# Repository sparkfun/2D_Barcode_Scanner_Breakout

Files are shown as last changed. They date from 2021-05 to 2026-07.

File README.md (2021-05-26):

2D Barcode Scanner Breakout
========================================

2D Barcode Scanner Breakout

[*2D Barcode Scanner Breakout (BOB-18088)*](https://www.sparkfun.com/products/18088)

The DYScan DE2120 is one of the coolest little barcode scanners we've ever seen. This tiny "scan engine" will read 20 different barcode symbologies — both 1D and 2D! This is achieved by using a camera coupled with on-board image processing to identify and decode everything from UPC codes to QR codes. The module also features two LEDs: one for illumination and one to project the red line that you're used to seeing from laser-based scanners. 

This breakout board makes it easy to explore all of the capabilities of the DE2120 without dealing with finicky flat flex cables. The scanner's USB interface is exposed via the on-board USB-C connector. A buzzer and status LED are connected to the module through appropriate drive circuits and a pushbutton tactile switch is provided on the "trigger" pin. When you're ready to incorporate the module into your embedded project, you can leverage the 5 pin header for direct access to the TTL serial pins, power pins, and trigger input.

The module can be configured either by using the serial interface or by scanning command barcodes found in the datasheet.

Repository Contents
-------------------
* **/Documentation** - Datasheet & Settings Manual
* **/Hardware** - Eagle design files (.brd, .sch)

Documentation
--------------
* [SparkFun DE2120 Arduino Library](https://github.com/sparkfun/SparkFun_DE2120_Arduino_Library)
* [SparkFun DE2120 Python Package](https://github.com/sparkfun/DE2120_Py)
* [2D Barcode Scanner Breakout Hookup Guide](https://learn.sparkfun.com/tutorials/2d-barcode-scanner-breakout-hookup-guide)

Product Versions

* [BOB-18088](https://www.sparkfun.com/products/18088)
* [SPX-16441](https://www.sparkfun.com/products/16441)
* [SPX-16410](https://www.sparkfun.com/products/16410)

License Information
-------------------

This product is _**open source**_! 

Please review the LICENSE.md file for license information. 

If you have any questions or concerns on licensing, please contact technical support on our [SparkFun forums](https://forum.sparkfun.com/viewforum.php?f=152).

Distributed as-is; no warranty is given.

- Your friends at SparkFun.

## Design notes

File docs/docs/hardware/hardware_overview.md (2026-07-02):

# Hardware Overview

Let's take a closer look at the DYScan DE2290 scanner module as well as the other hardware on the 2d Barcode Scanner Breakout - V2.

## DE2290 Barcode Scanner Module

The DE2290 barcode scanner module from DYScan combines a CMOS camera with on-board image processing to identify and decode 20 different barcode symbologies in both 1D and 2D on a variety of mediums (paper, screen, etc.). The DE2290 also includes two user-configurable LEDs. One super bright white LED to help illuminate the scanning area and one red LED to project the red line like those found on laser-based scanners.

The DE2290 interfaces over USB Serial and TTL UART and can operate in several modes including USB Keyboard (default), USB COM, USB HID and TTL. Configure the communication modes and other settings by scanning barcodes or sending serial commands from the [Scan Settingss Manual](/ref/DY%20SCAN%202D%20barcode%20scanner%20DE2290D.%20DE2290H%20setting%20manual.pdf). 

When in USB Keyboard mode, the scanner behaves as a keyboard input (think your typical scanner on a Point of Sale system) and "types" the scanned barcode data followed by a carriage return. In USB-COM mode, the scanner behaves as a USB COM device and in TTL mode, the scanner operates as a TTL UART device to interface with a controller.

The module's two LEDs are also fully configurable to set behavior, brightness and simple on/off settings.

As mentioned above, the DE2290 can recognize and scan many different 1D and 2D symbologies. The list below outlines all the barcode symbologies the module recognizes:

**1D Symbologies**

* UPC-A
* UPC-E
* EAN-8
* EAN-13
* Code 128
* GS1-128
* Code 39
* Code 93
* Code 11
* Interleaved 2-of-5
* Matrix 2-of-5
* Industrial 2-of-5
* Codabar
* MSI
* GS1 DataBar
* Datalogic 2-of-5

**2D Symbologies**

* QR Code
* Data Matrix
* PDF 417
* Micro PDF 417
* Aztec Code

## Pinout and USB-C Connection

The scanner module receives power either via the USB-C connector or from a regulated **3.3V** source through the **3.3V** pin. The scanner requires at least **190mA@3.3V** to function. **5V** from USB is regulated to **3.3V** through an on-board **3.3V/600mA** regulator.

The breakout routes the power input pins (**3.3V** and Ground), Serial UART (RX/TX) pins as well as the Trigger Input and Status Output pins to a standard 0.1"-spaced PTH header to easily interface with them when integrating the module breakout in an installation. 

## Buzzer, Status LED and Trigger Button

We've routed the trigger pin to a pushbutton labeled SCAN, the status LED pin to a green LED and buzzer pin to a Piezo buzzer. Configure the Trigger and Buzzer just like everything else on the DE2290 using serial commands or barcodes from the [Scan Settings Manual](/ref/DY%20SCAN%202D%20barcode%20scanner%20DE2290D.%20DE2290H%20setting%20manual.pdf). 

Use the Trigger Button (or pin) to initiate a scan when the DE2290 is in Trigger Mode (default). The buzzer defaults to play a tone on power-up and on a successful decode. The STAT LED illuminates on power-up and on a successful scan. The STAT LED is not configurable through software but can be disabled through the STAT LED Jumper.

## Solder Jumpers

The 2D Barcode Scanner Breakout has three jumpers labeled <code>**PWR**</code>, <code>**STAT_LED**</code> and <code>**BUZZ**</code>. These three jumpers all complete their respective circuits and are **CLOSED** by default.

The Power LED Jumper connects the anode of the power LED to **3.3V** through a **1k&ohm;** resistor. Open the jumper by severing the trace between the two pads to disable the Power LED.

The STAT LED Jumper connects the anode of the status LED to a transistor via a **1k&ohm;** resistor so it can be controlled by the barcode module. Open the jumper to permanently disable the Status LED on the breakout. Disabling this LED is recommended if you are using an external LED connected to the STAT PTH pin.

The Buzzer Jumper completes the buzzer driver circuit and connects the voltage input (positive) pin of the buzzer to **3.3V** via a **10&ohm;** resistor. Open the jumper to disable the on board buzzer. Similar to the STAT LED, opening this jumper is particularly useful when an external buzzer is connected to the buzzer driver PTH pin.

## Board Dimensions

The 2D Barcode Scanner Breakout measures 1.75in x 1.00in (44.45mm x 25.4mm) with two mounting holes that fit a [4-40 screw](https://www.sparkfun.com/products/10453).

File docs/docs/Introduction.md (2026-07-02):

---
slug: /
---

# Introduction

<figure>
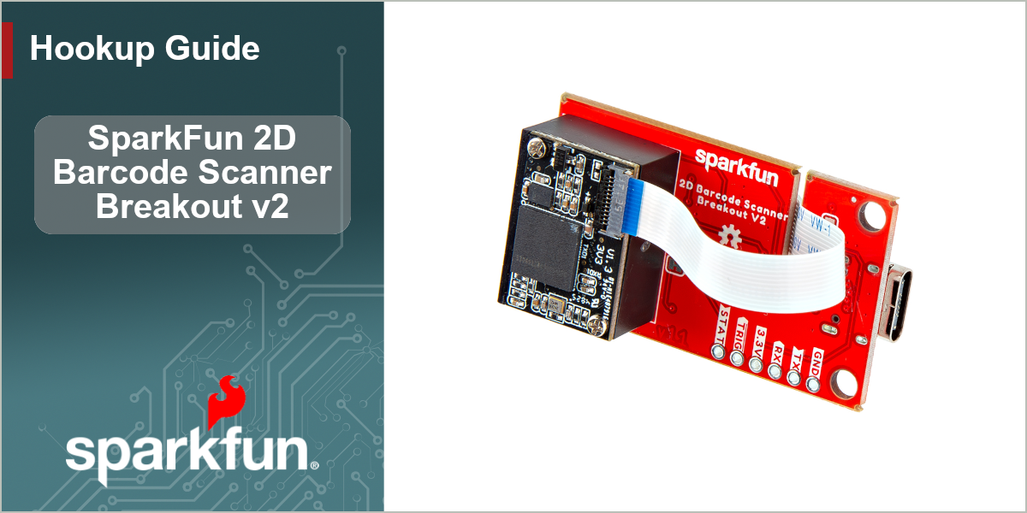
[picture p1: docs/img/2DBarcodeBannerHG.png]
2D Barcode Scanner Hookup Guide Banner Image (https://www.sparkfun.com/sparkfun-2d-barcode-scanner-breakout-v2.html)

</figure>

The [SparkFun 2D Barcode Scanner Breakout - V2](https://www.sparkfun.com/sparkfun-2d-barcode-scanner-breakout-v2.html) is a nifty little breakout board featuring the DE2290 barcode scanner module from DYScan. The DE2290 reads 20 different barcode symbologies (both 1D and 2D) using a camera coupled with on-board image processing to identify and decode everything from UPC codes to QR codes. The module also features two LEDs: one for illumination and one to project the red line for "aiming" that you're used to seeing from laser-based scanners.

The breakout makes it easy to use the scanner module by connecting the scanner's USB serial output to a USB-C connector. The breakout also includes a standard 0.1"-spaced PTH header for power, serial UART, trigger and status output connections. On top of that, we've added a trigger button, buzzer and status LED connected to the appropriate drive circuits to easily initialize scans and receive feedback from scanning barcodes.

**Note About Versions**

This version of the 2D Barcode Scanner Breakout (V2) is physically identical to the previous version and the DE2290 functions the same as the DE2120 but uses a different naming convention for the command set. This version works as a drop-in replacement but must use the updated commands. The previous version's Arduino library and Python package have been ported to new versions that use the DE2290 command set. The silkscreen on this version reads "2D Barcode Scanner V2". Refer to the image below to make sure you are using the correct version:

<figure>
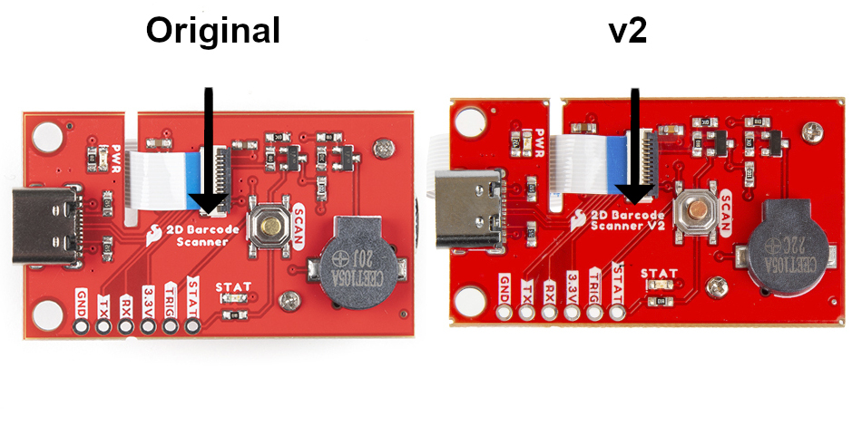
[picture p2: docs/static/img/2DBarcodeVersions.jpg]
Photo showing version indicator

</figure>

## Topics Covered

This guide contains three main sections: **Quickstart Guide**, **Hardware** and **Software**. 

The Quickstart Guide covers how to plug the Barcode Scanner Breakout into a computer over USB and use it as a COM device to scan codes and print them out in a serial terminal. 

The Hardware section provides a detailed overview of the DE2290 and other hardware on the 2D Barcode Scanner Breakout and covers how to connect the breakout to both a computer as well as a SparkFun RedBoard to use it with the Arduino IDE.

The Software section covers how to install the SparkFun DE2290 Arduino Library along with brief overviews of some of the examples included in the library.

## Resources and Support Documentation

You'll find the board design files (Eagle files & schematic), relevant documentation (datasheets, white papers, etc.) and other helpful links in the **Resources**. Lastly, the **Support** section includes a Troubleshooting page that includes any helpful tips specific to this board as well as information on how to receive technical support from SparkFun.

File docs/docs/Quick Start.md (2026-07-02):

# Quick Start Guide

In this Quick Start Guide we'll show how to connect the 2D Barcode Scanner - V2 to a computer over USB, operate it as a COM device to scan barcodes and print out the scanned codes to a serial terminal. This guide assumes users know how to interact with a COM device using a serial terminal. If you're unfamiliar with using serial terminals or would prefer to use the 

## USB Assembly

Start by connecting the Barcode Scanner Breakout to a computer with a USB-C cable. 

<figure>
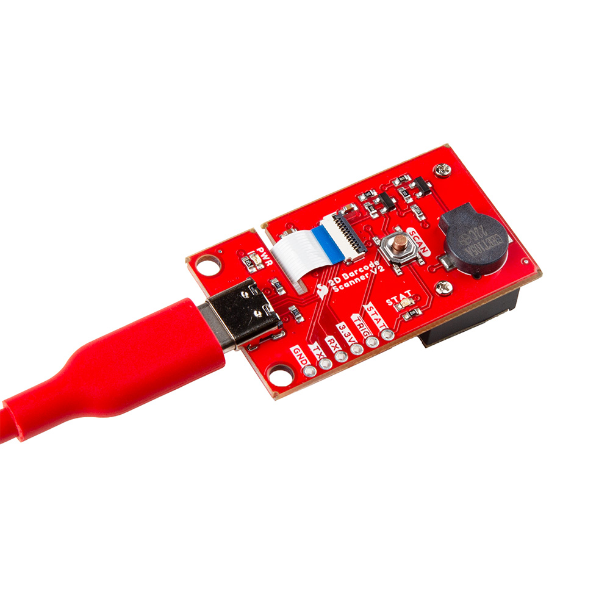
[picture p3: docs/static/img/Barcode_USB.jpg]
Barcode Scanner Breakout connected over USB

</figure>

Next, find scan the USB-COM Mode barcode from the [Scan Settings Manual](/ref/DY%20SCAN%202D%20barcode%20scanner%20DE2290D.%20DE2290H%20setting%20manual.pdf) (the DE2290 defaults to USB-Keyboard mode) on page 35 or you can scan it directly below:

<figure>
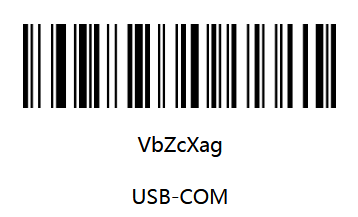
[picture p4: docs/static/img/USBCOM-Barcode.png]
USB-COM Mode barcode from the Scan Settingss Manual

</figure>

The DE2290 defaults to operate in Trigger Mode to scan barcodes so you'll need to press the trigger button to initiate a scan. Once the DE2290 is in USB-COM mode, your computer should automatically download and install the device's driver if needed. 

## Serial Terminal Scanning

With the drivers installed and the Barcode Scanner Breakout in USB-COM mode, open a serial terminal of your choice like [TeraTerm](https://teratermproject.github.io/index-en.html) to the COM port with the baud set to **115200**. 

The DE2290 defaults to operate in Trigger Mode to scan barcodes so you'll need to press the trigger button for each scan. Find some barcodes to scan or if you don't have any readily available, you can generate custom codes from all types of symbologies on [this website](https://barcode.tec-it.com/en) to make sure the barcode scanner is working properly.

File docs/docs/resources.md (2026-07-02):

For more information about the 2D Barcode Scanner Breakout v2, take a look at the following resources:

* [Schematic](/ref/2D_Barcode_Scanner_Breakout.pdf)
* [Eagle Files](/ref/2D_Barcode_Scanner_Breakout.zip)
* [Datasheet](/ref/DY%20SCAN%202D%20barcode%20module%20DE2290D%20Specification%20(1).pdf)
* [Scan Settings Manual](/ref/DY%20SCAN%202D%20barcode%20scanner%20DE2290D.%20DE2290H%20setting%20manual.pdf)
* [DE2290 Arduino Library](https://github.com/sparkfun/SparkFun_DE2290D_Arduino_Library)
* [DE2290 Python Package](https://github.com/sparkfun/DE2290D_Py)

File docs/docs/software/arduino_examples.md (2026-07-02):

# Arduino Examples

The DE2290 Library includes three examples to demonstrate how to do simple scans, read the barcode data, configure the various settings available and sending specific commands. In this section we'll go over these examples in some detail and highlight important bits of code.

**Important:** Make sure to scan the barcode below to put the DE2290 into TTL mode or the barcode scanner will not communicate properly with the Arduino and the examples will freeze until the board is reset.

<figure>
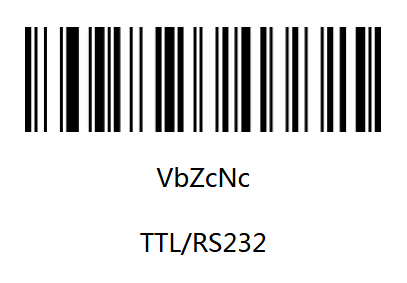
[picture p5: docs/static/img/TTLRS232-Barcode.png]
DE2290 TTL Mode Barcode
[]
</figure>

The 2D Barcode Scanner saves all settings during power cycles so you can configure the DE2290 however you would like (e.g. scanning mode, image flipping, LED settings, etc.) prior to assembling your Arduino circuit and using the examples.

## Example 1 - Serial Scan

This basic example demonstrates how to connect the scanner to an Arduino via Software Serial and output any barcodes it sees over serial. Open the example in Arduino by navigating to **"File > Examples > SparkFun DE2290 Arduino Library > 
Example1-SerialScan"**. Select the correct Board and Port from the **"Tools"** menu and click upload. After the upload finishes, open the [serial monitor](https://learn.sparkfun.com/tutorials/terminal-basics) with the baud set to **115200**.

Since this example uses the Software Serial library, make sure to refer to [this page](https://www.arduino.cc/en/Reference/softwareSerial) for pin compatibility limitations for common Arduino boards. The example defaults to use pins D16 and D17 on the RedBoard IoT - ESP32 so if you prefer a different board, adjust this line:

``` c++
SoftwareSerial softSerial(2, 3);
```

After declaring the pins to use for RX/TX in Software Serial, the code creates the scanner object as well as the scanner buffer and buffer size:

``` c++
DE2290 scanner;
    
#define BUFFER_LEN 40
char scanBuffer[BUFFER_LEN];
```
The setup attempts to initialize the barcode scanner and, if successful, the main loop will start polling the buffer for any data every 200ms. If there is data in the buffer, the code prints it. With a serial monitor open, try scanning barcodes with the breakout and watch the code data print out.

## Example 2 - Serial Settings

The second example shows how to adjust a selection of seven scanner settings using a "menu" in the serial monitor. Select and upload the example and open a serial monitor with the baud set to **115200**. After initializing the DE2290, the code prints out the selection options for the user.

<figure>
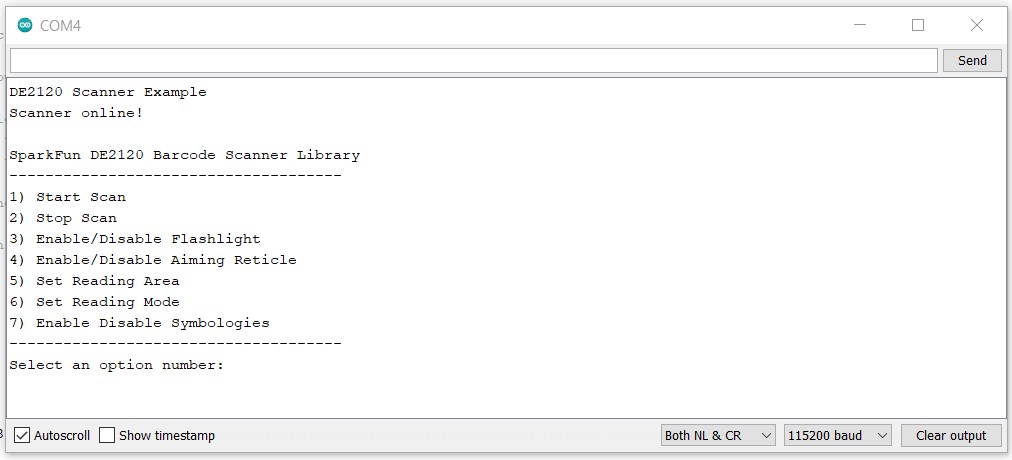
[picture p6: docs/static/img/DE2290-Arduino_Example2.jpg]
Screenshot showing Arduino Serial Monitor of options menu

</figure>

Select an option number by sending the corresponding number and hit <kbd>ENTER</kbd>. The code then prints out the available options for the selected setting. Enter the number corresponding to the preferred behavior and hit <kbd>ENTER</kbd> again to change the setting. After the setting is adjusted, the code prints if the adjustment was successful and returns to the "main menu".

## Example 3 - Send Command

The third example demonstrates how to use the `sendCommand();` function to send serial commands to the barcode scanner either through scanning barcodes or a serial monitor. As we mentioned in the previous section, `sendCommand();` takes two strings, links them together, adds the command prefix ("^_^") and suffix (".") and sends the command to the DE2290. 

Upload the example and open the serial monitor with the baud set to **115200**. Once the terminal window is open, type in the command you want to use and press <kbd>ENTER</kbd>. Refer to the [Scan Settingss Manual](/ref/DY%20SCAN%202D%20barcode%20scanner%20DE2290D.%20DE2290H%20setting%20manual.pdf) for the Command Table (found starting on page 78). If the command is not recognized, the code prints out the code is invalid.

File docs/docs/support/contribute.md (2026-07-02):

# Contribute

## Improve our Documentation

All of this documentation can be modified by you! Please help us make it better.

* These pages are contained in the [`docs` folder of the SparkFun 2D Barcode Scanner Breakout repository](https://github.com/sparkfun/2D_Barcode_Scanner_Breakout/tree/main/docs).

### Submit a Correction

1. Fork this repo
2. Add your corrections or improvements to the markdown file
3. File a pull request with your changes, and enjoy making the ~~words~~ ~~worlds~~ world a better place.
    * Once received, the documentation specialist will automatically be notified.
    * We will review your suggested improvements to make sure they are correct and fit within our documentation standards.

## Improve our Hardware Design

This hardware design is open-source! Please help us make it better.

* Our board design files are contained in the [`Hardware` folder of the SparkFun 2D Barcode Scanner Breakout repository](https://github.com/sparkfun/2D_Barcode_Scanner_Breakout_IoT_9DoF/tree/main/Hardware).

### Submit a Design Improvement

1. Fork this repo
2. Add your design improvements
3. File a pull request with your changes, and enjoy making the ~~words~~ ~~worlds~~ world a better place.
    * Once received, the engineer in charge of the original design will automatically be notified.
    * We will review your suggested improvements, if they are within our board design standards and meet our product design requirements, we will flag these changes for our next board revision. *(Please note, that even if your suggestion is accepted, these changes may not be immediate. We may have to cycle through our current product inventory first.)*

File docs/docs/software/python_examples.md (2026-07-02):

# DE2290 Python Package Examples

The DE2290 Python package includes three examples to demonstrate the basics of using the 2D Barcode Scanner Breakout with Python. In this section we'll cover the examples and highlight how they work.

To use the examples, open them from the DE2290 Py location or copy the code from the [GitHub Repository](https://github.com/sparkfun/DE2290_Py/tree/main/examples) into your preferred Python interpreter.

**Reminder:** The DE2290 Python Package communicates with the 2D Barcode Scanner Breakout over USB so make sure to set the DE2290 to USB-COM mode by scanning the barcode below or sending the appropriate serial command:

<figure>
DE2290 TTL Mode Barcode
</figure>

The 2D Barcode Scanner saves all settings during power cycles so you can configure the DE2290 however you would like (e.g. scanning mode, image flipping, LED settings, etc.) prior to using the examples.

## Example 1 - Serial Scan

This basic example demonstrates how to initialize the barcode scanner and output any barcodes it reads. The example attempts to initialize the barcode scanner and, if successful, starts polling the buffer for any data every 200ms. If there is data in the buffer, the code prints it. With a terminal window open to the correct port, try scanning barcodes with the breakout and watch the decoded barcode data print out.

## Example 2 - Serial Settings

This example shows how to configure various settings for the DE2290 using serial inputs sent over USB. The code creates an interactive menu for starting and stopping a scan along with the settings listed below:

* Enable/Disable Flashlight
* Enable/Disable Aiming Reticle
* Enable/Disable Decode Beep
* Enable/Disable Start Up Beep
* Change Buzzer Frequency
* Enablde/Disable Image Flipping
* Set Reading Area
* Set Reading Mode
* Enable/Disable Symbologies

Run the example and open a terminal window to the Barcode Scanner's port. To adjust a setting, type in the corresponding number and hit ENTER. A second menu for will open with the available options for the setting. Type in the number matching the preferred option and hit ENTER again. The code prints out if the setting is adjusted successfully and then returns to the main menu.

## Example 3 - Send Command

The third example demonstrates how to use the `send_command` function to send specific command strings to the DE2290. The `send_command` function takes two strings, links them together, adds the command prefix ("^_^") and suffix (".") and sends the command to the DE2290. 

Run the example and open a terminal window to the Barcode Scanner's port. Once the terminal window is open, type in the command you want to use and press ENTER. Refer to the [Scan Settings Manual](/ref/DY%20SCAN%202D%20barcode%20scanner%20DE2290D.%20DE2290H%20setting%20manual.pdf) for the Command Table. If the command is not recognized, the code prints out the code is invalid.

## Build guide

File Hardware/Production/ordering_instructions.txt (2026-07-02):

panel size, 111x117mm
PCB thickness, 1.6mm
number of layers, 2
soldermask color, Red
silkscreen color, White
oz copper, 1oz
finish, HASL lead free
stencils, top
pcs per panel, 8
min trace width, 0.1778mm / 0.0070in
min drill size, 0.3810mm / 0.0150in

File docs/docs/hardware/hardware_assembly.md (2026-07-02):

# Hardware Assembly

Now that we're familiar with the DE2290 and other hardware present on the 2D Barcode Scanner Breakout, let's get it connected and start scanning codes.

## USB Assembly

The easiest way to get started with the barcode scanner breakout is to plug it in to a computer (PC or SBC) via a USB-C cable. Simply connect the breakout to your computer using a USB-C cable and scan the USB-COM mode barcode from the [Scan Settings Manual](/ref/DY%20SCAN%202D%20barcode%20scanner%20DE2290D.%20DE2290H%20setting%20manual.pdf) (the DE2290 defaults to USB-Keyboard mode) on page 23 or you can scan directly it below:

<figure>
USB-COM Mode barcode from the Scan Settingss Manual
</figure>

Once the device is in USB-COM Mode your computer should automatically search for and install the necessary drivers. After drivers are installed and the device has enumerated, select the correct port and open up a terminal window with the baud to **115200**. 

The DE2290 defaults to trigger mode to scan barcodes so the Trigger Button must be pressed to start a scan. Find some barcodes to scan or if you don't have any readily available, you can generate custom codes from all types of symbologies on [this website](https://barcode.tec-it.com/en) to quickly test the barcode scanner. 

<figure>
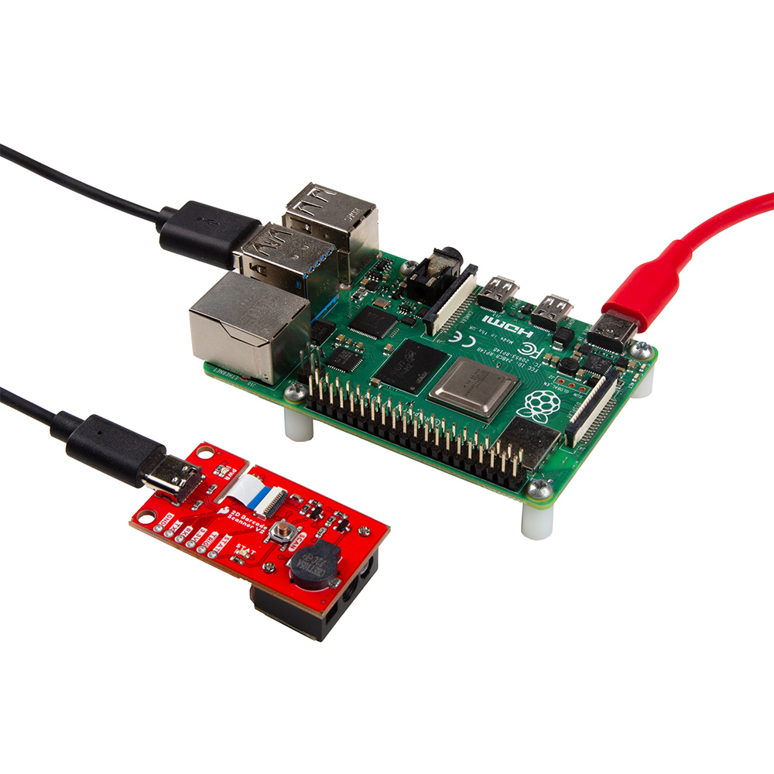
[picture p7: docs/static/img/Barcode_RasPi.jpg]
Completed USB assembly with a Raspberry Pi

</figure>

## Serial UART Assembly

Interacting with the 2D Barcode Scanner Breakout via TTL UART either through direct commands from the Scan Settings Manual or with the Arduino library requires a bit of soldering and wiring. As covered in the previous seciton, the breakout routes the required TTL UART pins to a 0.1"-spaced header for users to solder to. If you are not familiar with through-hole soldering, we recommend reading through [this tutorial](https://learn.sparkfun.com/tutorials/how-to-solder-through-hole-soldering). **Reminder:** The barcode scanner requires **190mA@3.3V** so make sure your chosen microcontroller can source enough current through the **3.3V** output to power the scanner.

For easy prototyping in this tutorial we're going to solder a set of [male headers](https://www.sparkfun.com/products/116) to the breakout to easily prototype circuits using either a breadboard or jumper wires. After soldering to the breakout, we make the necessary connections to the controller. In this case we'll use a SparkFun RedBoard to demonstrate the Arduino library so make the following connections or match the photo below:

* **3.3V** -> **3.3V**
* **GND** -> **Ground**
* **TX** -> **16**
* **RX** -> **17**

<figure>
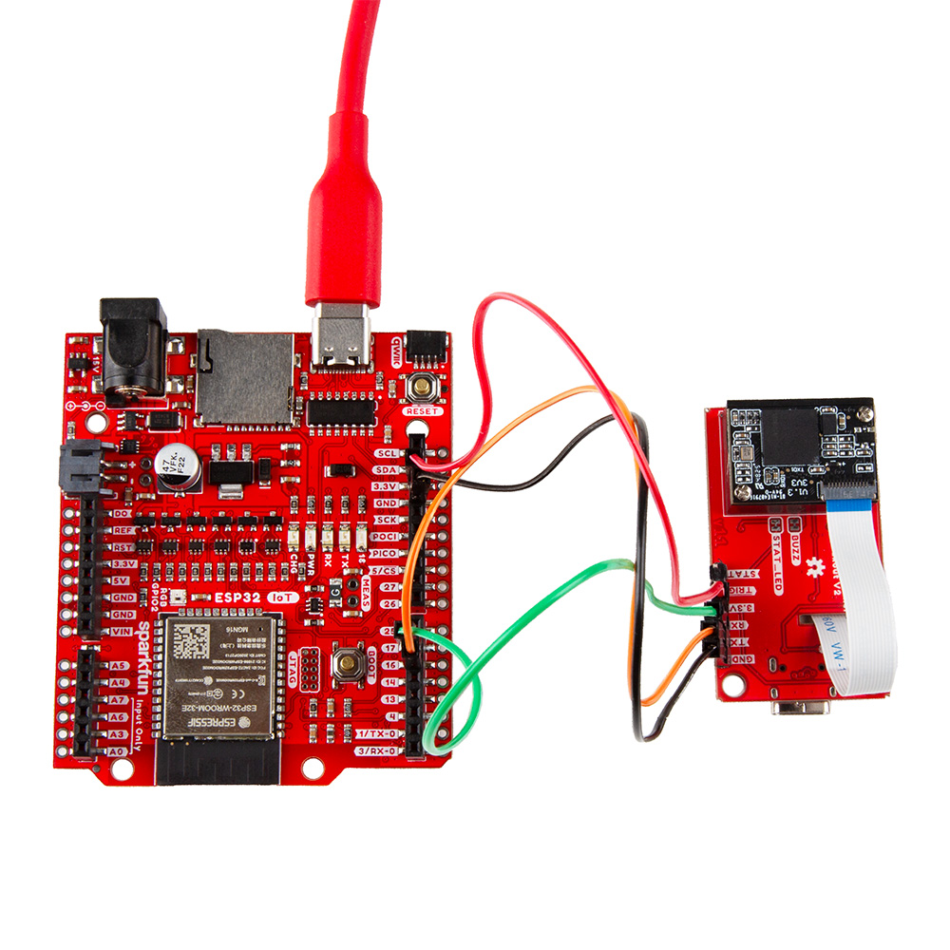
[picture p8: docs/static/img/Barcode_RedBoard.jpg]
Completed assembly with the RedBoard IoT

</figure>

After assembling the circuit, make sure to set the 2D Barcode Scanner Breakout to operate in TTL mode by scanning the proper barcode from the [Scan Settings Manual](/ref/DY%20SCAN%202D%20barcode%20scanner%20DE2290D.%20DE2290H%20setting%20manual.pdf) on page 24 or you can scan it with the barcode reader below:

<figure>
DE2290 TTL Mode Barcode
</figure>

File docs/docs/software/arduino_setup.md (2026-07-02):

# DE2290 Arduino Library Setup

## SparkFun DE2290

The SparkFun DE2290 Arduino Library helps to interface an Arduino microcontroller with the barcode scanner to configure common settings as well as poll the device for scanned codes. Note, the library does not cover all of the codes from the [Scan Settings Manual](/ref/DY%20SCAN%202D%20barcode%20scanner%20DE2290D.%20DE2290H%20setting%20manual.pdf); just the ones we found particularly useful.

Install the Arduino Library Manager by searching for **"SparkFun DE2290 Arduino Library"** and clicking the "Install" button to download and install the latest version. Users who prefer to manually install the library can get it from the [GitHub Repository](https://github.com/sparkfun/SparkFun_DE2290_Arduino_Library).

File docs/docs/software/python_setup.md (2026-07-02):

# DE2290 Python Package Setup

The SparkFun DE2290 Python package helps streamline sending commands and receiving barcode data from the 2D Barcode Scanner Breakout. Install the `sparkfun-de2290d` Python package hosted by PyPi through a command interface or if you prefer to manually download and build the libraries from the [GitHub Repository](https://github.com/sparkfun/DE2290D_Py), 

## Installation

The Raspberry Pi OS should automatically install any necessary drivers for the 2D Barcode Scanner when it is connected and operating in USB-COM Mode. Find the USB-COM barcode on page 23 in the [Scan Settings Manual](/ref/DY%20SCAN%202D%20barcode%20scanner%20DE2290D.%20DE2290H%20setting%20manual.pdf) (the DE22900 defaults to USB-Keyboard mode) or scan it below:

<figure>
USB-COM Mode barcode from the Scan Settingss Manual
</figure>

### PyPi Installation

The DE2290 Py repository is hosted on PyPi as the `sparkfun-de22902` package. On systems that support PyPi, install the package via `pip3` (use `pip` for Python 2) using the following commands:

For **all users** (The user must have **[sudo](https://en.wikipedia.org/wiki/Sudo)** privileges):

``` bash
    sudo pip3 install sparkfun-DE2290
```

For the **current user**:

``` bash
    pip3 install sparkfun-DE2290
```
### Local Installation

Make sure to install the `setuptools` package on the system.

Direct installation at the command line (use `python` for Python 2):

``` bash
    python3 setup.py install
```    
Use the following command to build a package for use with `pip3`:

``` bash
    python3 steup.py sdist
```

A package file is built and placed in a subdirectory called dist. Install the package file using `pip3`.

``` bash
    cd dist
    pip3 install sparkfun_DE2290-<version>.tar.gz
```
### DE2290 Python Package Operation

For a full overview of how to use this package along with all the functions included with the DE2290 Py package, take a look at the [source code](https://github.com/sparkfun/DE2290D_Py/blob/main/de2290D_barcode_scanner.py).

### Upgrading the Python Package

If needed, the DE2290 Python package can be upgraded using the following commands:

For **all users**:

``` bash
    sudo pip3 install --upgrade sparkfun-DE2290
```

For the **current user**:

``` bash
    pip3 install --upgrade sparkfun-DE2290
```

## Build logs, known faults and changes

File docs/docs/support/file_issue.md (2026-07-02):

# Submit Issues

## Support

If you need technical assistance and more information on a product that is not working as you expected, visit the [SparkFun Community](https://community.sparkfun.com). The community forums are monitored by the SparkFun Technical Support Team and the SparkFun community as a whole.

## Existing Issue

Spot something wrong? Please check the list of reported and fixed issues  .  in this repository.

## Discrepancies in the Documentation

All of this documentation can be modified by you! Please help us make it better.

* The documentation files for these pages are contained in the [`docs` folder of the SparkFun 2D Barcode Scanner Breakout repository](https://github.com/sparkfun/2D_Barcode_Scanner_Breakout/tree/main/docs).

### Spot something wrong?

If a section of the documentation is incorrect, please [open an issue](https://github.com/sparkfun/2D_Barcode_Scanner_Breakout/issues) and let us know.

### Do you have a suggested correction?

1. With a GitHub account, fork this repo
2. Add your correction(s) or improvement(s) to the markdown file(s)
3. File a pull request with your changes, and enjoy making the ~~words~~ ~~worlds~~ world a better place.
    * Once received, the documentation specialist will automatically be notified.
    * We will review your suggested improvement(s) to make sure they are correct and fit within our documentation standards.

## Problems in the Hardware Design

All of our designs are open-source! Please help us make it better.

* Our board design files are contained in the [`Hardware` folder of the SparkFun 2D Barcode Scanner Breakout repository](https://github.com/sparkfun/2D_Barcode_Scanner_Breakout/tree/main/Hardware).

### Does something not make sense?

If part of the design is confusing, please [open an issue](https://github.com/sparkfun/2D_Barcode_Scanner_Breakout/issues) and let us know.

### Did we forget to include an important function of the board?

Please keep in mind that we may intentionally exclude certain functions of the board to meet our product design requirements.

If part of the board's functionality is missing, please [open an issue](https://github.com/sparkfun/2D_Barcode_Scanner_Breakout/issues) and file a feature request.

### Do you wish to contribute directly to improving the board design?

1. With a GitHub account, Fork this repo
2. Add your design improvement(s)
3. File a pull request with your changes, and enjoy making the ~~words~~ ~~worlds~~ world a better place.
    * Once received, the engineer in charge of the original design will automatically be notified.
    * We will review your suggested improvement(s), if they are within our board design standards and meet our product design requirements, we will flag these changes for our next board revision. *(Please note, that even if your suggestion is accepted, these changes may not be immediate. We may have to cycle through our current product inventory first.)*

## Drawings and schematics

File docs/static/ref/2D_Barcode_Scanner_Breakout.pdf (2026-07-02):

3.3V

## 3.3V GND

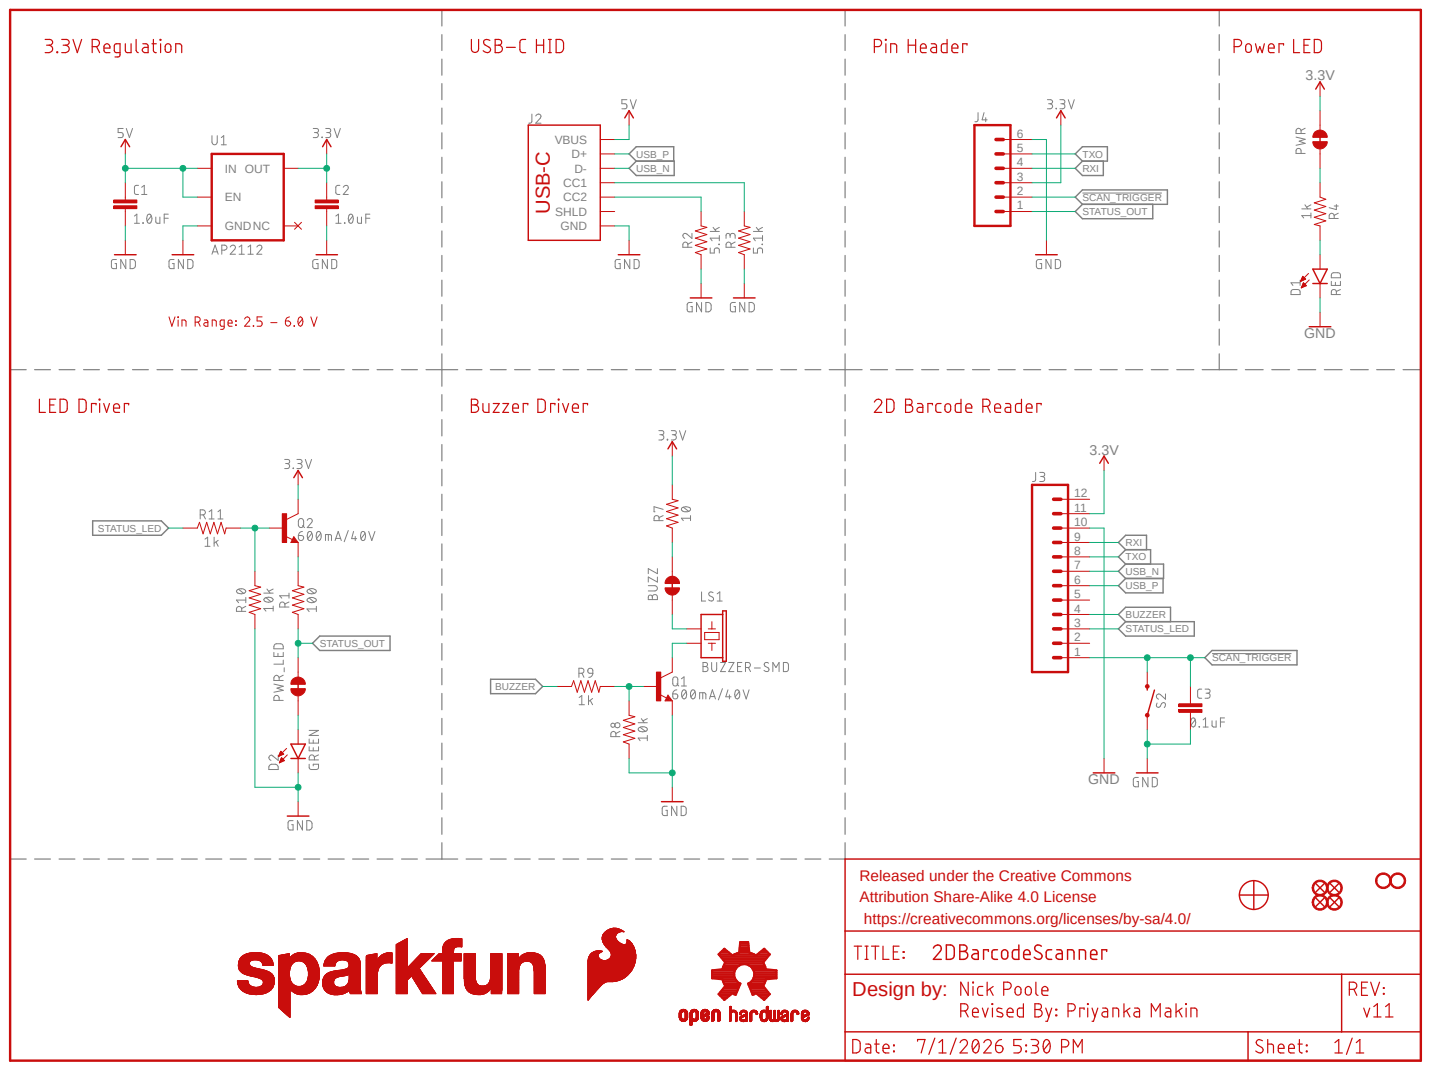
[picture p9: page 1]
GND; VBUS CC1 D+D- CC2 SHLD; INGNDOUT EN; 12 TXO; TXO; RXI; BUZZER; STATUS_LED; SCAN_TRIGGER; USB_N; USB_P; STATUS_OUT; USB⁻C; Design by:

Released under the Creative Commons
Attribution Share-Alike 4.0 License
https://creativecommons.org/licenses/by-sa/4.0/

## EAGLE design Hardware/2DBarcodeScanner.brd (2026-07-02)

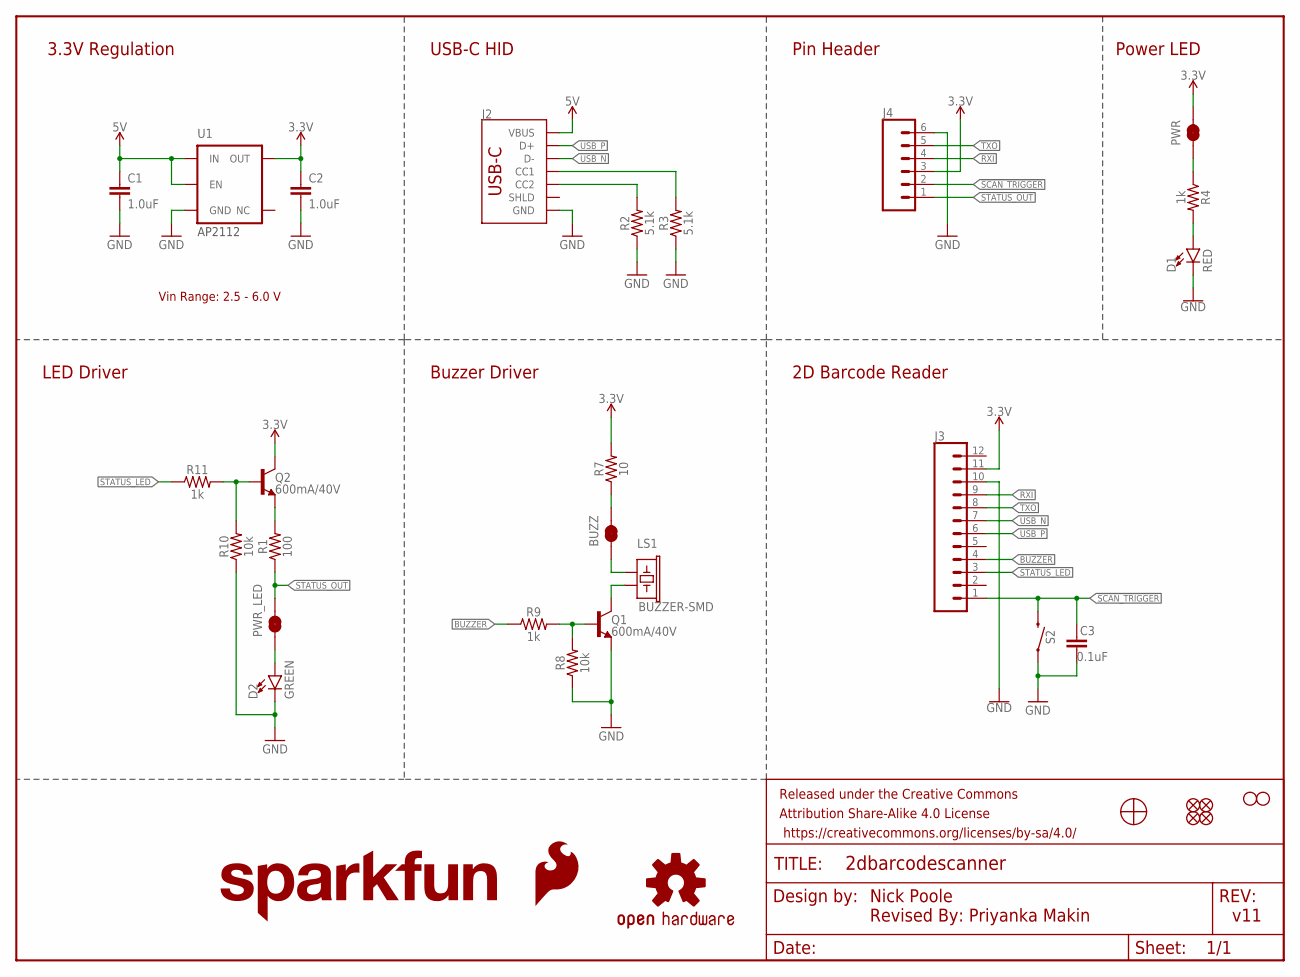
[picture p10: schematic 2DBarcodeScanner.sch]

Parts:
BUZZ: JUMPER-SMT_2_NC_TRACE_SILK; SMT-JUMPER_2_NC_TRACE_SILK
C1, C2: 1.0uF; 0603
C3: 0.1uF; 0603
D1: RED; LED-0603
D2: GREEN; LED-0603
FD1, FD2, FD3, FD4: FIDUCIALUFIDUCIAL; FIDUCIAL-MICRO
FRAME1: FRAME-LETTER; CREATIVE_COMMONS
H2, H3: STAND-OFF
J2: USB_C_2-LAYER_PADS; USB-C-16P-2LAYER-PADS
J3: CONN_12FPC_12_0.5MM; FPC_12_0.5MM
J4: CONN_06NO_SILK_FEMALE_PTH; 1X06_NO_SILK
LOGO1: OSHW-LOGOS; OSHW-LOGO-S
LOGO2: SFE_LOGO_FLAME.1_INCH; SFE_LOGO_FLAME_.1
LOGO3: SFE_LOGO_NAME.1_INCH; SFE_LOGO_NAME_.1
LS1: BUZZER-SMD; BUZZER-CCV
PWR: JUMPER-SMT_2_NC_TRACE_SILK; SMT-JUMPER_2_NC_TRACE_SILK
PWR_LED: JUMPER-SMT_2_NC_TRACE_SILK; SMT-JUMPER_2_NC_TRACE_SILK
Q1, Q2: 600mA/40V; SOT23-3
R1: 100; 0603
R2, R3: 5.1k; 0603
R4, R9, R11: 1k; 0603
R7: 10; 0603
R8, R10: 10k; 0603
S2: MOMENTARY-SWITCH-SPST-SMD-5.2MM-TALL; TACTILE_SWITCH_SMD_5.2MM
U1: 3.3V; SOT23-5
U2: BARCODE_SCANNER_MOUNT

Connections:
3.3V: C2.1, J3.11, J4.3, PWR.2, Q2.3 (C), R7.2, U1.5 (OUT)
5V: C1.1, J2.VBUS1 (VBUS), J2.VBUS2 (VBUS), U1.1 (IN), U1.3 (EN)
!SCAN_TRIGGER!: C3.1, J3.1, J4.2, S2.3 (2)
BUZZER: J3.4, R9.1
CC3: J2.A5 (CC1), R3.2
CC4: J2.B5 (CC2), R2.2
GND: C1.2, C2.2, C3.2, D1.C, D2.C, J2.GND, J2.GND2 (GND), J3.10, J4.6, Q1.2 (E), R2.1, R3.1, R8.1, R10.1, S2.1, U1.2 (GND)
unnamed: BUZZ.2, R7.1
unnamed: LS1.- (2), Q1.3 (C)
unnamed: BUZZ.1, LS1.+ (1)
unnamed: Q2.2 (E), R1.2
unnamed: Q1.1 (B), R8.2, R9.2
unnamed: PWR.1, R4.1
unnamed: Q2.1 (B), R10.2, R11.2
unnamed: D2.A, PWR_LED.1
unnamed: D1.A, R4.2
RXI: J3.9, J4.4
STATUS_LED: J3.3, R11.1
STATUS_OUT: J4.1, PWR_LED.2, R1.1
TXO: J3.8, J4.5
USB_N: J2.A7 (D-), J2.B7 (D-), J3.7
USB_P: J2.A6 (D+), J2.B6 (D+), J3.6

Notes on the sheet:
3.3V Regulation
AP2112
Pin Header
2D Barcode Reader
LED Driver
Buzzer Driver
USB-C HID
Power LED
Nick Poole Revised By: Priyanka Makin
v11
Vin Range: 2.5 - 6.0 V

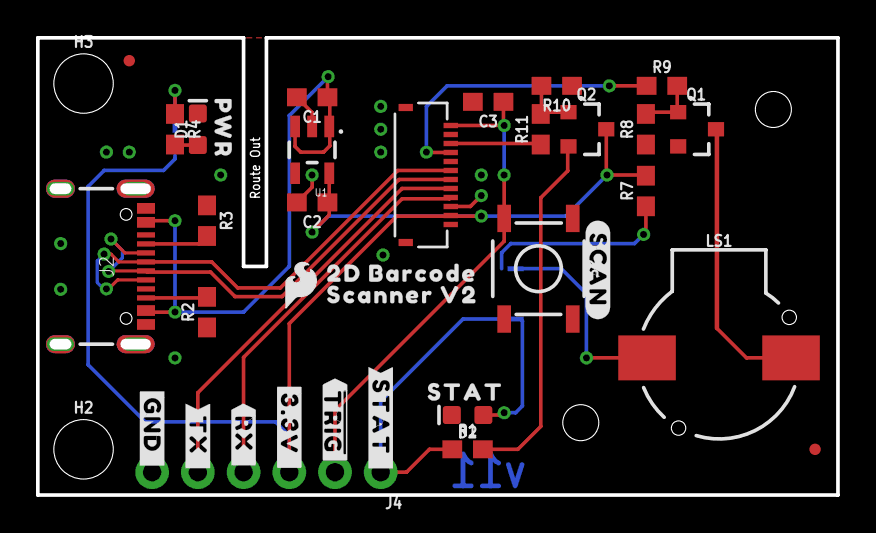
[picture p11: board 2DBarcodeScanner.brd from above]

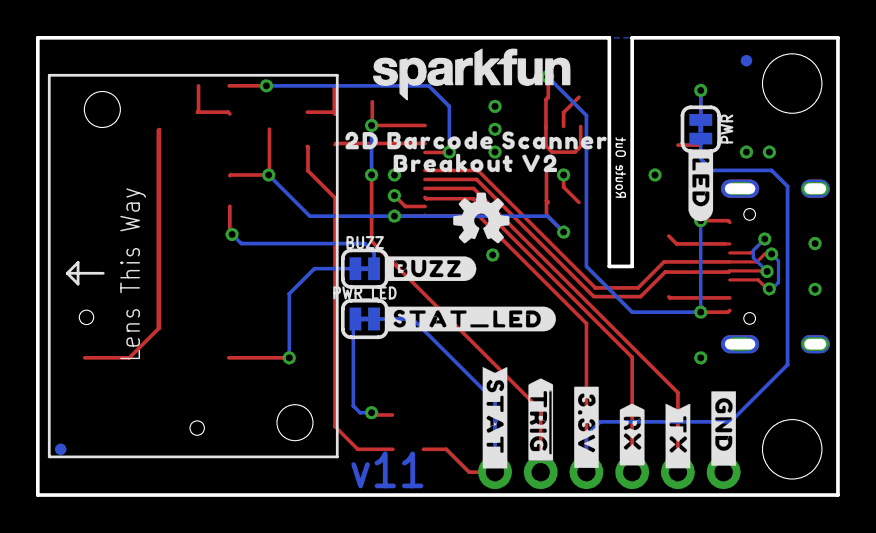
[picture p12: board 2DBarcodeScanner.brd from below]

Board: 2 copper layers, 44.5 x 25.4 mm, 58 parts (19 on the bottom side), 22 nets.

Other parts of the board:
U$1, U$7: ##TRIG##0
U$2, U$21: #STAT_#0
U$3: STAT0
U$4: #SCAN#0
U$5: #BUZZ#0
U$6: #STAT_LED#0
U$8: PWR0
U$9: #LED#0
U$10: SCANNER_V20
U$11: BREAKOUT_V20
U$12: 2D_BARCODE_SCANNER0
U$17: 2D_BARCODE0
U$26, U$27: #TX_#0
U$28, U$29: #3#3V_#0
U$30, U$31: #RX_#0
U$32, U$33: #GND_#0

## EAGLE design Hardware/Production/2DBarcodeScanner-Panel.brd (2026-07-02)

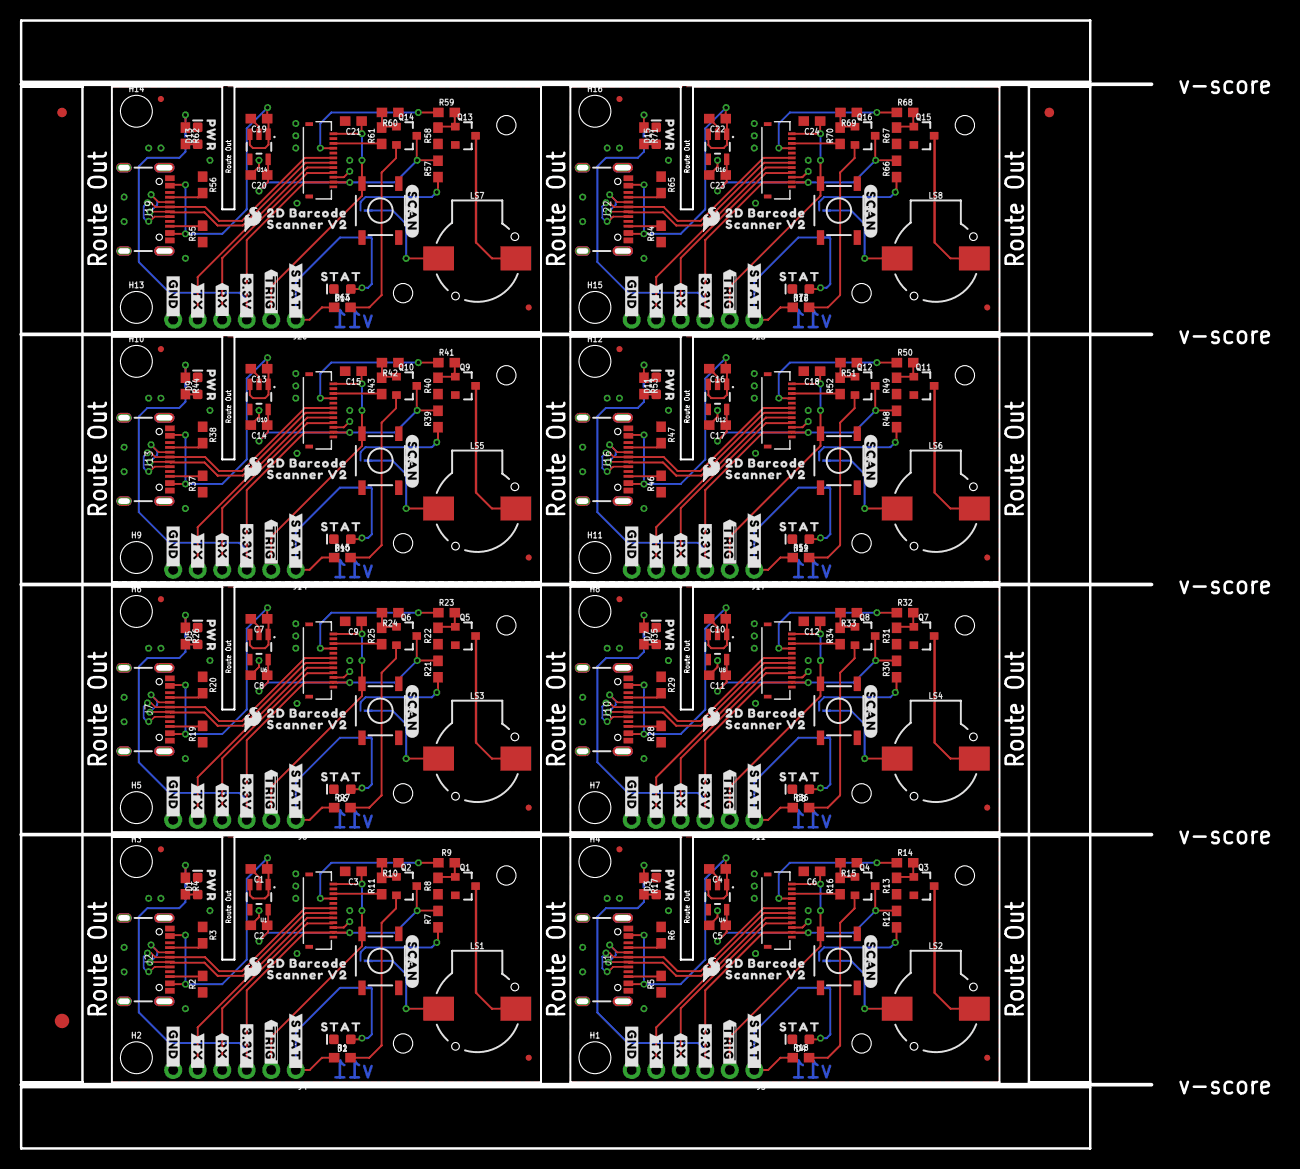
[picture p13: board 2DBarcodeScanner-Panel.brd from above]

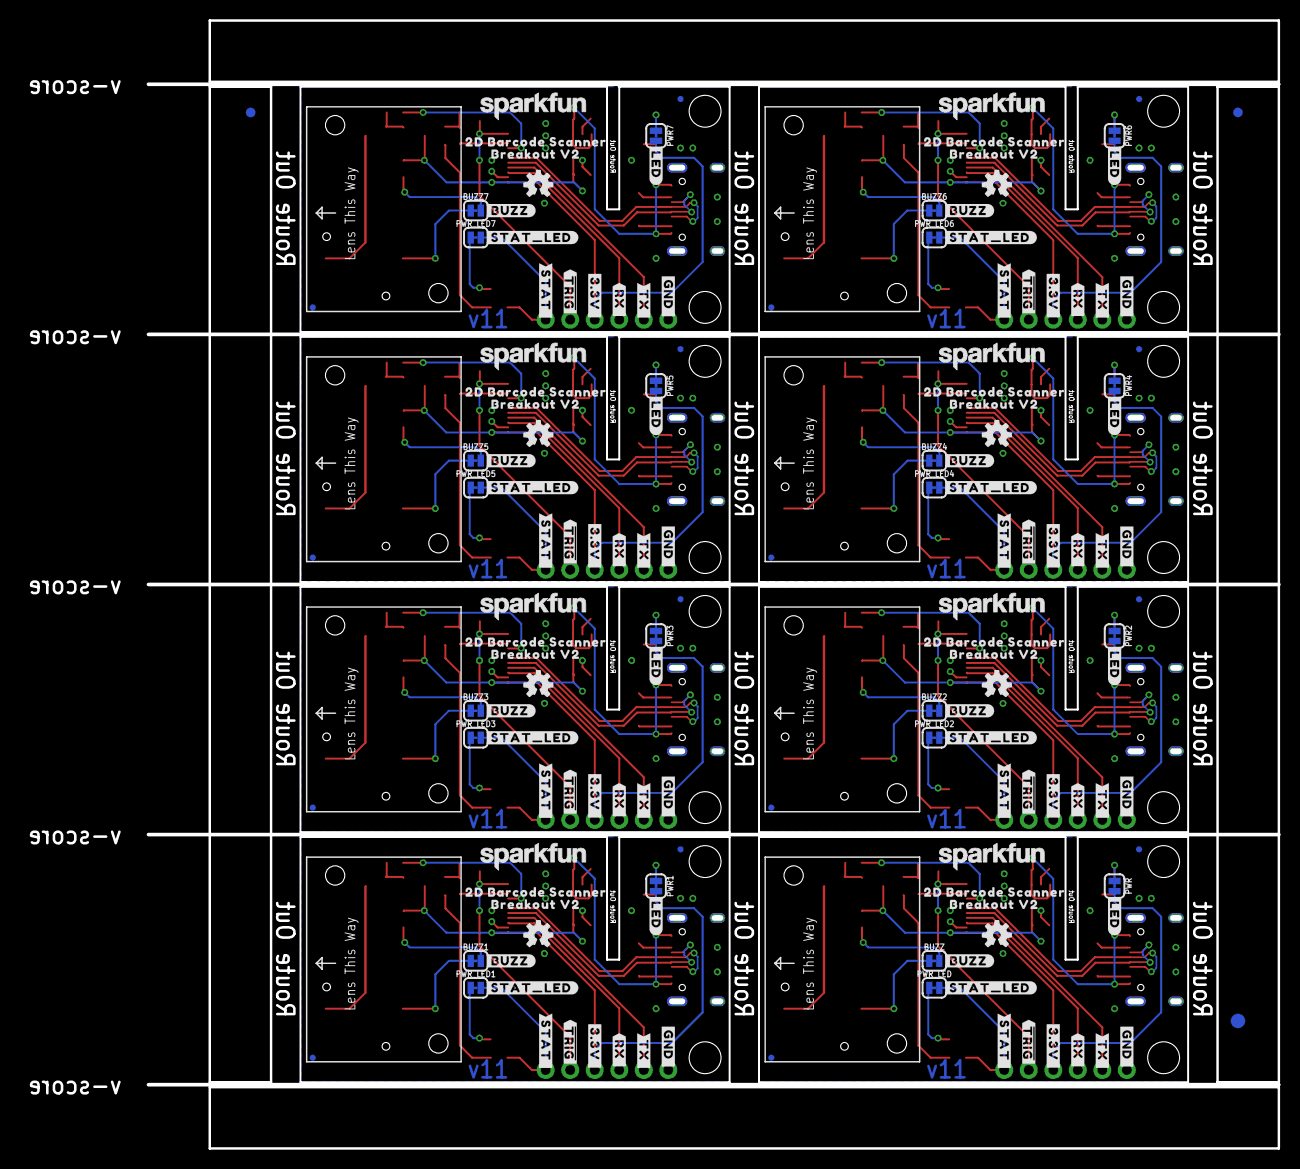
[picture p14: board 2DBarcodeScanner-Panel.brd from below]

Board: 2 copper layers, 117.1 x 116.8 mm, 462 parts (155 on the bottom side), 176 nets.

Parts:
BUZZ, BUZZ1, BUZZ2, BUZZ3, BUZZ4, BUZZ5, BUZZ6, BUZZ7: JUMPER-SMT_2_NC_TRACE_SILK; SMT-JUMPER_2_NC_TRACE_SILK
C1, C2, C4, C5, C7, C8, C10, C11, C13, C14, C16, C17, C19, C20, C22, C23: 1.0uF; 0603
C3, C6, C9, C12, C15, C18, C21, C24: 0.1uF; 0603
D1, D3, D5, D7, D9, D11, D13, D15: RED; LED-0603
D2, D4, D6, D8, D10, D12, D14, D16: GREEN; LED-0603
E$1, E$2, E$3, E$4: FIDUCIAL-1X2
E$5, E$6: FIDUCIAL-1.5X3
FD1, FD2, FD3, FD4, FD5, FD6, FD7, FD8, FD9, FD10, FD11, FD12, FD13, FD14, FD15, FD16, FD17, FD18, FD19, FD20, FD21, FD22, FD23, FD24, FD25, FD26, FD27, FD28, FD29, FD30, FD31, FD32: FIDUCIALUFIDUCIAL; FIDUCIAL-MICRO
H1, H2, H3, H4, H5, H6, H7, H8, H9, H10, H11, H12, H13, H14, H15, H16: STAND-OFF
J1, J2, J7, J10, J13, J16, J19, J22: USB-C-16P-2LAYER-PADS
J3, J6, J9, J12, J15, J18, J21, J24: FPC_12_0.5MM
J4, J5, J8, J11, J14, J17, J20, J23: 1X06_NO_SILK
LOGO1, LOGO4, LOGO7, LOGO10, LOGO13, LOGO16, LOGO19, LOGO22: OSHW-LOGOS; OSHW-LOGO-S
LOGO2, LOGO5, LOGO8, LOGO11, LOGO14, LOGO17, LOGO20, LOGO23: SFE_LOGO_FLAME.1_INCH; SFE_LOGO_FLAME_.1
LOGO3, LOGO6, LOGO9, LOGO12, LOGO15, LOGO18, LOGO21, LOGO24: SFE_LOGO_NAME.1_INCH; SFE_LOGO_NAME_.1
LS1, LS2, LS3, LS4, LS5, LS6, LS7, LS8: BUZZER-SMD; BUZZER-CCV
PWR, PWR1, PWR2, PWR3, PWR4, PWR5, PWR6, PWR7: JUMPER-SMT_2_NC_TRACE_SILK; SMT-JUMPER_2_NC_TRACE_SILK
PWR_LED, PWR_LED1, PWR_LED2, PWR_LED3, PWR_LED4, PWR_LED5, PWR_LED6, PWR_LED7: JUMPER-SMT_2_NC_TRACE_SILK; SMT-JUMPER_2_NC_TRACE_SILK
Q1, Q2, Q3, Q4, Q5, Q6, Q7, Q8, Q9, Q10, Q11, Q12, Q13, Q14, Q15, Q16: 600mA/40V; SOT23-3
R1, R18, R27, R36, R45, R54, R63, R72: 100; 0603
R2, R3, R5, R6, R19, R20, R28, R29, R37, R38, R46, R47, R55, R56, R64, R65: 5.1k; 0603
R4, R9, R11, R14, R16, R17, R23, R25, R26, R32, R34, R35, R41, R43, R44, R50, R52, R53, R59, R61, R62, R68, R70, R71: 1k; 0603
R7, R12, R21, R30, R39, R48, R57, R66: 10; 0603
R8, R10, R13, R15, R22, R24, R31, R33, R40, R42, R49, R51, R58, R60, R67, R69: 10k; 0603
S1, S2, S3, S4, S5, S6, S7, S8: MOMENTARY-SWITCH-SPST-SMD-5.2MM-TALL; TACTILE_SWITCH_SMD_5.2MM
U1, U4, U6, U8, U10, U12, U14, U16: 3.3V; SOT23-5
U2, U3, U5, U7, U9, U11, U13, U15: BARCODE_SCANNER_MOUNT
U$1, U$7, U$40, U$41, U$62, U$63, U$84, U$85, U$106, U$107, U$128, U$129, U$150, U$151, U$172, U$173: ##TRIG##0
U$2, U$13, U$16, U$21, U$45, U$48, U$67, U$70, U$89, U$92, U$111, U$114, U$133, U$136, U$155, U$158: #STAT_#0
U$3, U$14, U$46, U$68, U$90, U$112, U$134, U$156: STAT0
U$4, U$35, U$57, U$79, U$101, U$123, U$145, U$167: #SCAN#0
U$5, U$36, U$58, U$80, U$102, U$124, U$146, U$168: #BUZZ#0
U$6, U$39, U$61, U$83, U$105, U$127, U$149, U$171: #STAT_LED#0
U$8, U$37, U$59, U$81, U$103, U$125, U$147, U$169: PWR0
U$9, U$38, U$60, U$82, U$104, U$126, U$148, U$170: #LED#0
U$10, U$42, U$64, U$86, U$108, U$130, U$152, U$174: SCANNER_V20
U$11, U$43, U$65, U$87, U$109, U$131, U$153, U$175: BREAKOUT_V20
U$12, U$44, U$66, U$88, U$110, U$132, U$154, U$176: 2D_BARCODE_SCANNER0
U$15, U$17, U$47, U$69, U$91, U$113, U$135, U$157: 2D_BARCODE0
U$18, U$19, U$28, U$29, U$49, U$50, U$71, U$72, U$93, U$94, U$115, U$116, U$137, U$138, U$159, U$160: #3#3V_#0
U$20, U$22, U$26, U$27, U$51, U$52, U$73, U$74, U$95, U$96, U$117, U$118, U$139, U$140, U$161, U$162: #TX_#0
U$23, U$24, U$30, U$31, U$53, U$54, U$75, U$76, U$97, U$98, U$119, U$120, U$141, U$142, U$163, U$164: #RX_#0
U$25, U$32, U$33, U$34, U$55, U$56, U$77, U$78, U$99, U$100, U$121, U$122, U$143, U$144, U$165, U$166: #GND_#0

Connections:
3.3V: C2.1, J3.11, J4.3, PWR.2, Q2.3, R7.2, U1.5
3.3V1: C5.1, J5.3, J6.11, PWR1.2, Q4.3, R12.2, U4.5
3.3V2: C8.1, J8.3, J9.11, PWR2.2, Q6.3, R21.2, U6.5
3.3V3: C11.1, J11.3, J12.11, PWR3.2, Q8.3, R30.2, U8.5
3.3V4: C14.1, J14.3, J15.11, PWR4.2, Q10.3, R39.2, U10.5
3.3V5: C17.1, J17.3, J18.11, PWR5.2, Q12.3, R48.2, U12.5
3.3V6: C20.1, J20.3, J21.11, PWR6.2, Q14.3, R57.2, U14.5
3.3V7: C23.1, J23.3, J24.11, PWR7.2, Q16.3, R66.2, U16.5
5V: C1.1, J2.VBUS1, J2.VBUS2, U1.1, U1.3
5V1: C4.1, J1.VBUS1, J1.VBUS2, U4.1, U4.3
5V2: C7.1, J7.VBUS1, J7.VBUS2, U6.1, U6.3
5V3: C10.1, J10.VBUS1, J10.VBUS2, U8.1, U8.3
5V4: C13.1, J13.VBUS1, J13.VBUS2, U10.1, U10.3
5V5: C16.1, J16.VBUS1, J16.VBUS2, U12.1, U12.3
5V6: C19.1, J19.VBUS1, J19.VBUS2, U14.1, U14.3
5V7: C22.1, J22.VBUS1, J22.VBUS2, U16.1, U16.3
!SCAN_TRIGGER!: C3.1, J3.1, J4.2, S2.3
!SCAN_TRIGGER!1: C6.1, J5.2, J6.1, S1.3
!SCAN_TRIGGER!2: C9.1, J8.2, J9.1, S3.3
!SCAN_TRIGGER!3: C12.1, J11.2, J12.1, S4.3
!SCAN_TRIGGER!4: C15.1, J14.2, J15.1, S5.3
!SCAN_TRIGGER!5: C18.1, J17.2, J18.1, S6.3
!SCAN_TRIGGER!6: C21.1, J20.2, J21.1, S7.3
!SCAN_TRIGGER!7: C24.1, J23.2, J24.1, S8.3
BUZZER: J3.4, R9.1
BUZZER1: J6.4, R14.1
BUZZER2: J9.4, R23.1
BUZZER3: J12.4, R32.1
BUZZER4: J15.4, R41.1
BUZZER5: J18.4, R50.1
BUZZER6: J21.4, R59.1
BUZZER7: J24.4, R68.1
CC1: J1.A5, R6.2
CC2: J1.B5, R5.2
CC3: J2.A5, R3.2
CC4: J2.B5, R2.2
CC5: J7.A5, R20.2
CC6: J7.B5, R19.2
CC7: J10.A5, R29.2
CC8: J10.B5, R28.2
CC9: J13.A5, R38.2
CC10: J13.B5, R37.2
CC11: J16.A5, R47.2
CC12: J16.B5, R46.2
CC13: J19.A5, R56.2
CC14: J19.B5, R55.2
CC15: J22.A5, R65.2
CC16: J22.B5, R64.2
GND: C1.2, C2.2, C3.2, D1.C, D2.C, J2.GND, J2.GND2, J3.10, J4.6, Q1.2, R2.1, R3.1, R8.1, R10.1, S2.1, U1.2
GND1: C4.2, C5.2, C6.2, D3.C, D4.C, J1.GND, J1.GND2, J5.6, J6.10, Q3.2, R5.1, R6.1, R13.1, R15.1, S1.1, U4.2
GND2: C7.2, C8.2, C9.2, D5.C, D6.C, J7.GND, J7.GND2, J8.6, J9.10, Q5.2, R19.1, R20.1, R22.1, R24.1, S3.1, U6.2
GND3: C10.2, C11.2, C12.2, D7.C, D8.C, J10.GND, J10.GND2, J11.6, J12.10, Q7.2, R28.1, R29.1, R31.1, R33.1, S4.1, U8.2
GND4: C13.2, C14.2, C15.2, D9.C, D10.C, J13.GND, J13.GND2, J14.6, J15.10, Q9.2, R37.1, R38.1, R40.1, R42.1, S5.1, U10.2
GND5: C16.2, C17.2, C18.2, D11.C, D12.C, J16.GND, J16.GND2, J17.6, J18.10, Q11.2, R46.1, R47.1, R49.1, R51.1, S6.1, U12.2
GND6: C19.2, C20.2, C21.2, D13.C, D14.C, J19.GND, J19.GND2, J20.6, J21.10, Q13.2, R55.1, R56.1, R58.1, R60.1, S7.1, U14.2
GND7: C22.2, C23.2, C24.2, D15.C, D16.C, J22.GND, J22.GND2, J23.6, J24.10, Q15.2, R64.1, R65.1, R67.1, R69.1, S8.1, U16.2
unnamed: BUZZ.2, R7.1
unnamed: LS1.-, Q1.3
unnamed: BUZZ.1, LS1.+
unnamed: Q2.2, R1.2
unnamed: Q1.1, R8.2, R9.2
unnamed: PWR.1, R4.1
unnamed: Q2.1, R10.2, R11.2
unnamed: D2.A, PWR_LED.1
unnamed: D1.A, R4.2
unnamed: LS2.-, Q3.3
unnamed: Q3.1, R13.2, R14.2
unnamed: Q4.2, R18.2
unnamed: Q4.1, R15.2, R16.2
unnamed: D4.A, PWR_LED1.1
unnamed: BUZZ1.2, R12.1
unnamed: BUZZ1.1, LS2.+
unnamed: PWR1.1, R17.1
unnamed: D3.A, R17.2
unnamed: LS3.-, Q5.3
unnamed: Q5.1, R22.2, R23.2
unnamed: Q6.2, R27.2
unnamed: Q6.1, R24.2, R25.2
unnamed: D6.A, PWR_LED2.1
unnamed: BUZZ2.2, R21.1
unnamed: BUZZ2.1, LS3.+
unnamed: PWR2.1, R26.1
unnamed: D5.A, R26.2
unnamed: LS4.-, Q7.3
unnamed: Q7.1, R31.2, R32.2
unnamed: Q8.2, R36.2
unnamed: Q8.1, R33.2, R34.2
unnamed: D8.A, PWR_LED3.1
unnamed: BUZZ3.2, R30.1
unnamed: BUZZ3.1, LS4.+
unnamed: PWR3.1, R35.1
unnamed: D7.A, R35.2
unnamed: LS5.-, Q9.3
unnamed: Q9.1, R40.2, R41.2
unnamed: Q10.2, R45.2
unnamed: Q10.1, R42.2, R43.2
unnamed: D10.A, PWR_LED4.1
unnamed: BUZZ4.2, R39.1
unnamed: BUZZ4.1, LS5.+
unnamed: PWR4.1, R44.1
unnamed: D9.A, R44.2
unnamed: LS6.-, Q11.3
unnamed: Q11.1, R49.2, R50.2
unnamed: Q12.2, R54.2
unnamed: Q12.1, R51.2, R52.2
unnamed: D12.A, PWR_LED5.1
unnamed: BUZZ5.2, R48.1
unnamed: BUZZ5.1, LS6.+
unnamed: PWR5.1, R53.1
unnamed: D11.A, R53.2
unnamed: LS7.-, Q13.3
unnamed: Q13.1, R58.2, R59.2
unnamed: Q14.2, R63.2
unnamed: Q14.1, R60.2, R61.2
unnamed: D14.A, PWR_LED6.1
unnamed: BUZZ6.2, R57.1
unnamed: BUZZ6.1, LS7.+
unnamed: PWR6.1, R62.1
unnamed: D13.A, R62.2
unnamed: LS8.-, Q15.3
unnamed: Q15.1, R67.2, R68.2
unnamed: Q16.2, R72.2
unnamed: Q16.1, R69.2, R70.2
unnamed: D16.A, PWR_LED7.1
unnamed: BUZZ7.2, R66.1
unnamed: BUZZ7.1, LS8.+
unnamed: PWR7.1, R71.1
unnamed: D15.A, R71.2
RXI: J3.9, J4.4
RXI1: J5.4, J6.9
RXI2: J8.4, J9.9
RXI3: J11.4, J12.9
RXI4: J14.4, J15.9
RXI5: J17.4, J18.9
RXI6: J20.4, J21.9
RXI7: J23.4, J24.9
STATUS_LED: J3.3, R11.1
STATUS_LED1: J6.3, R16.1
STATUS_LED2: J9.3, R25.1
STATUS_LED3: J12.3, R34.1
STATUS_LED4: J15.3, R43.1
STATUS_LED5: J18.3, R52.1
STATUS_LED6: J21.3, R61.1
STATUS_LED7: J24.3, R70.1
STATUS_OUT: J4.1, PWR_LED.2, R1.1
STATUS_OUT1: J5.1, PWR_LED1.2, R18.1
STATUS_OUT2: J8.1, PWR_LED2.2, R27.1
STATUS_OUT3: J11.1, PWR_LED3.2, R36.1
STATUS_OUT4: J14.1, PWR_LED4.2, R45.1
STATUS_OUT5: J17.1, PWR_LED5.2, R54.1
STATUS_OUT6: J20.1, PWR_LED6.2, R63.1
STATUS_OUT7: J23.1, PWR_LED7.2, R72.1
TXO: J3.8, J4.5
TXO1: J5.5, J6.8
TXO2: J8.5, J9.8
TXO3: J11.5, J12.8
TXO4: J14.5, J15.8
TXO5: J17.5, J18.8
TXO6: J20.5, J21.8
TXO7: J23.5, J24.8
USB_N: J2.A7, J2.B7, J3.7
USB_N1: J1.A7, J1.B7, J6.7
USB_N2: J7.A7, J7.B7, J9.7
USB_N3: J10.A7, J10.B7, J12.7
USB_N4: J13.A7, J13.B7, J15.7
USB_N5: J16.A7, J16.B7, J18.7
USB_N6: J19.A7, J19.B7, J21.7
USB_N7: J22.A7, J22.B7, J24.7
USB_P: J2.A6, J2.B6, J3.6
USB_P1: J1.A6, J1.B6, J6.6
USB_P2: J7.A6, J7.B6, J9.6
USB_P3: J10.A6, J10.B6, J12.6
USB_P4: J13.A6, J13.B6, J15.6
USB_P5: J16.A6, J16.B6, J18.6
USB_P6: J19.A6, J19.B6, J21.6
USB_P7: J22.A6, J22.B6, J24.6

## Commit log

2021-03-30 Update SPX design for reds
    Changes made:
    Switched out 12-pin ribbon cable connector for the one used on the RTK
    Added jumper on the buzzer
    Added power LED
    Updated names/version numbers
    Added fiducials
    AND updated the barcode scanner footprint/silk
    [2DBarcodeScanner.brd, 2DBarcodeScanner.sch]
2021-03-30 Update silkscreen
    [2DBarcodeScanner.brd, 2DBarcodeScanner.sch]
2021-03-30 Ran schematic/board checklists
    [2DBarcodeScanner.brd, 2DBarcodeScanner.sch]
2021-03-30 Change out green stat LED for yellow
    Pull-up resistor 470 --> 1k ohm
    [2DBarcodeScanner.brd, 2DBarcodeScanner.sch]
2021-03-30 Switch yellow stat LED out for blue
    [2DBarcodeScanner.brd, 2DBarcodeScanner.sch]
2021-04-01 Design Review Changes
    Update schematic frame
    Dimension width 0.008
    Increased width of GND polygon
    Moved v10 label on bottom
    Moved bottom jumpers in-line
    Added measures
    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
    [2DBarcodeScanner.brd, 2DBarcodeScanner.sch]
2021-04-02 QC Double Check Changes
    [2DBarcodeScanner.brd, 2DBarcodeScanner.sch]
2021-04-02 Panelize and generate gerbers
    [2DBarcodeScanner-Panel.GBL, 2DBarcodeScanner-Panel.GBO, 2DBarcodeScanner-Panel.GBP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]
2021-04-30 Flip TX and RX pins
    [2DBarcodeScanner.brd, 2DBarcodeScanner.sch]
2021-04-30 Update version number and re-panelize v11
    [2DBarcodeScanner-Panel.brd, 2DBarcodeScanner.brd, 2DBarcodeScanner.sch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]
2021-05-21 Switch status LED from blue to green and change pull-up to 100 ohms
    [2DBarcodeScanner.brd, 2DBarcodeScanner.sch]
2021-05-21 Re-panelize for BOM change
    [2DBarcodeScanner-Panel.brd]
2026-02-10 Update silk for V2 board
    [2DBarcodeScanner.brd]
2026-02-24 misc update
    [2DBarcodeScanner.sch]
2026-02-24 Add new production files with silk change
    [2DBarcodeScanner.GBL, 2DBarcodeScanner.GBO, 2DBarcodeScanner.GBP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]
2026-02-26 Add gerbers for new scanner
    [2DBarcodeScanner-Panel.GBL, 2DBarcodeScanner-Panel.GBO, 2DBarcodeScanner-Panel.GBS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]

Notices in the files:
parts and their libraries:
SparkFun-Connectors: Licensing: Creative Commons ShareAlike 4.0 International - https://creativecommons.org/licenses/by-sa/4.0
